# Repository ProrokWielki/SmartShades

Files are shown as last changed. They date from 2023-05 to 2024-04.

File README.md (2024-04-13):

# SmartShades

ESP-12F based project which enables to convert any standard shades into smart shades.

It communicates using mqtt and allows controlling the shades position

### What you need

* ESP-12F - or compatible device
* DRV8220DSG
* motor with encoder
* LM117-3.3
* capacitors and resistors

###

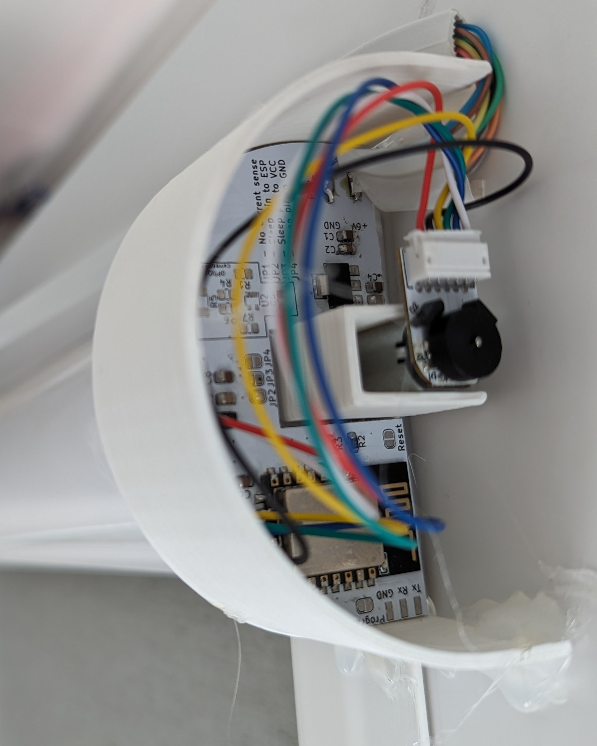
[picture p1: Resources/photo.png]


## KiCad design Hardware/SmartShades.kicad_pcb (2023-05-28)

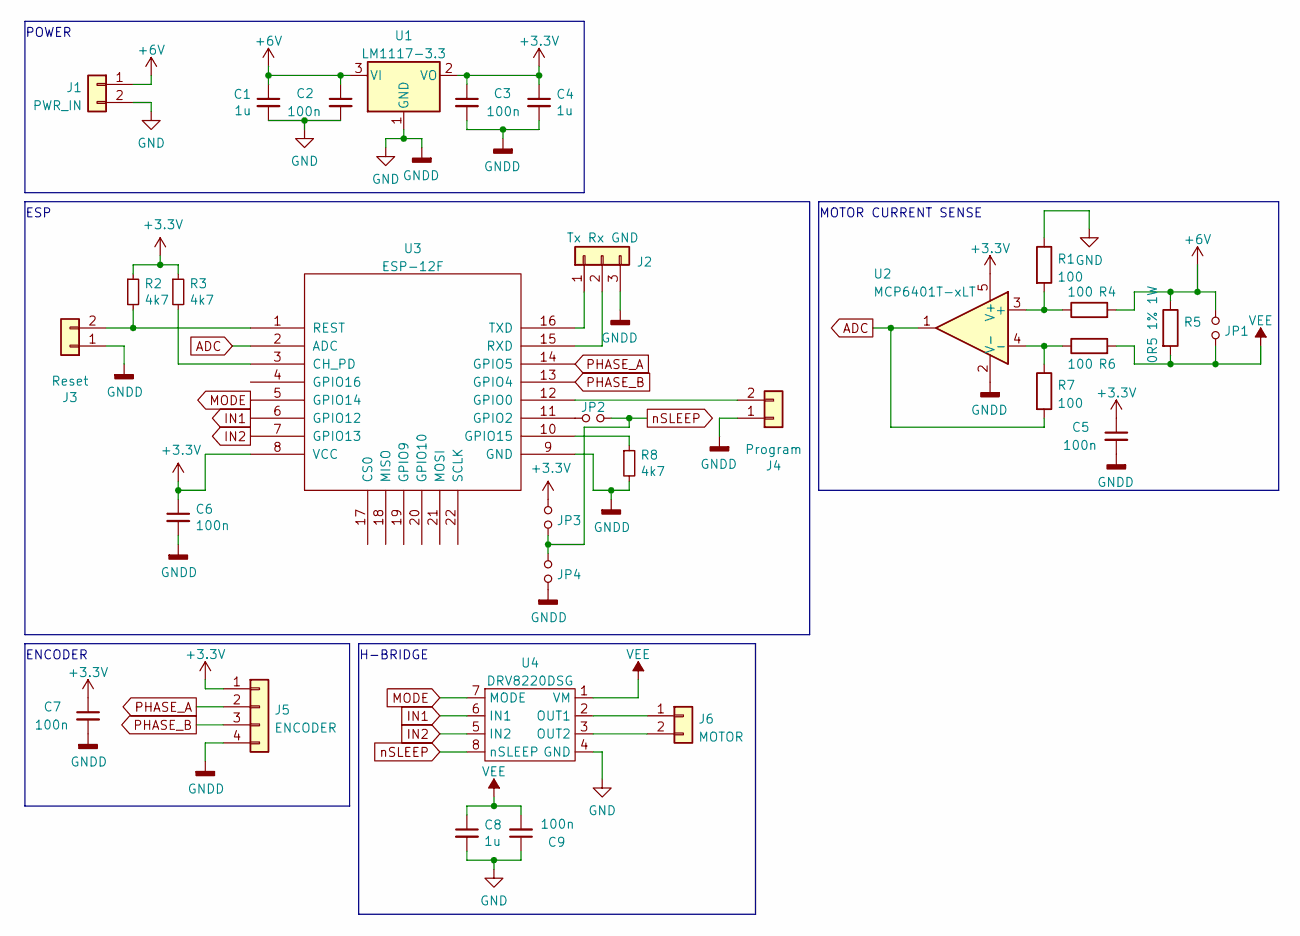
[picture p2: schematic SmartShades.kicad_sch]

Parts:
C1, C4, C8: 1u; C_0805_2012Metric
C2, C3, C5, C6, C7, C9: 100n; C_0805_2012Metric
J1: PWR_IN; TerminalBlock_Altech_AK300-2_P5.00mm
J2: Tx Rx GND; Harwin_M20-89003xx_1x03_P2.54mm_Horizontal
J3: Reset; SolderJumper-2_P1.3mm_Open_RoundedPad1.0x1.5mm
J4: Program; SolderJumper-2_P1.3mm_Open_RoundedPad1.0x1.5mm
J5: ENCODER; Harwin_M20-89004xx_1x04_P2.54mm_Horizontal
J6: MOTOR; Harwin_M20-89003xx_1x03_P2.54mm_Horizontal
JP1, JP2, JP3, JP4: Jumper_NO_Small; SolderJumper-2_P1.3mm_Open_RoundedPad1.0x1.5mm
R1, R4, R6, R7: 100; R_0805_2012Metric
R2, R3, R8: 4k7; R_0805_2012Metric
R5: 0R5 1% 1W; R_1206_3216Metric
U1: LM1117-3.3; SOT-223-3_TabPin2
U2: MCP6401T-xLT; SOT-353_SC-70-5
U3: ESP-12F; ESP-12E_SMD
U4: DRV8220DSG; WSON-8-1EP_2x2mm_P0.5mm_EP0.9x1.6mm

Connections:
+3V3: C3.1, C4.1, C5.1, C6.1, C7.1, J5.1, JP3.1, R2.1, R3.1, U1.2 (VO), U2.5 (V+), U3.8 (VCC)
+6V: C1.1, C2.1, J1.1, JP1.1, R4.2, R5.1, U1.3 (VI)
ADC: R7.2, U2.1, U3.2 (ADC)
GND: C1.2, C2.2, C3.2, C4.2, C5.2, C6.2, C7.2, C8.2, C9.1, J1.2, J2.3, J3.1, J4.1, J5.4, JP4.2, R1.1, R8.2, U1.1 (GND), U2.2 (V-), U3.9 (GND), U4.4 (GND), U4.9 (Pad)
IN1: U3.6 (GPIO12), U4.6 (IN1)
IN2: U3.7 (GPIO13), U4.5 (IN2)
MODE: U3.5 (GPIO14), U4.7 (MODE)
unnamed: J6.1, U4.2 (OUT1)
unnamed: J6.2, U4.3 (OUT2)
unnamed: JP2.1, U3.11 (GPIO2)
unnamed: R1.2, R4.1, U2.3 (+)
unnamed: R6.1, R7.1, U2.4 (-)
unnamed: J3.2, R2.2, U3.1 (REST)
unnamed: R3.2, U3.3 (CH_PD)
unnamed: R8.1, U3.10 (GPIO15)
unnamed: J4.2, U3.12 (GPIO0)
unnamed: J2.2, U3.15 (RXD)
unnamed: J2.1, U3.16 (TXD)
PHASE_A: J5.2, U3.14 (GPIO5)
PHASE_B: J5.3, U3.13 (GPIO4)
VEE: C8.1, C9.2, JP1.2, R5.2, R6.2, U4.1 (VM)
nSLEEP: JP2.2, JP3.2, JP4.1, U4.8 (nSLEEP)

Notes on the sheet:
POWER
MOTOR CURRENT SENSE
ENCODER
H-BRIDGE
ESP

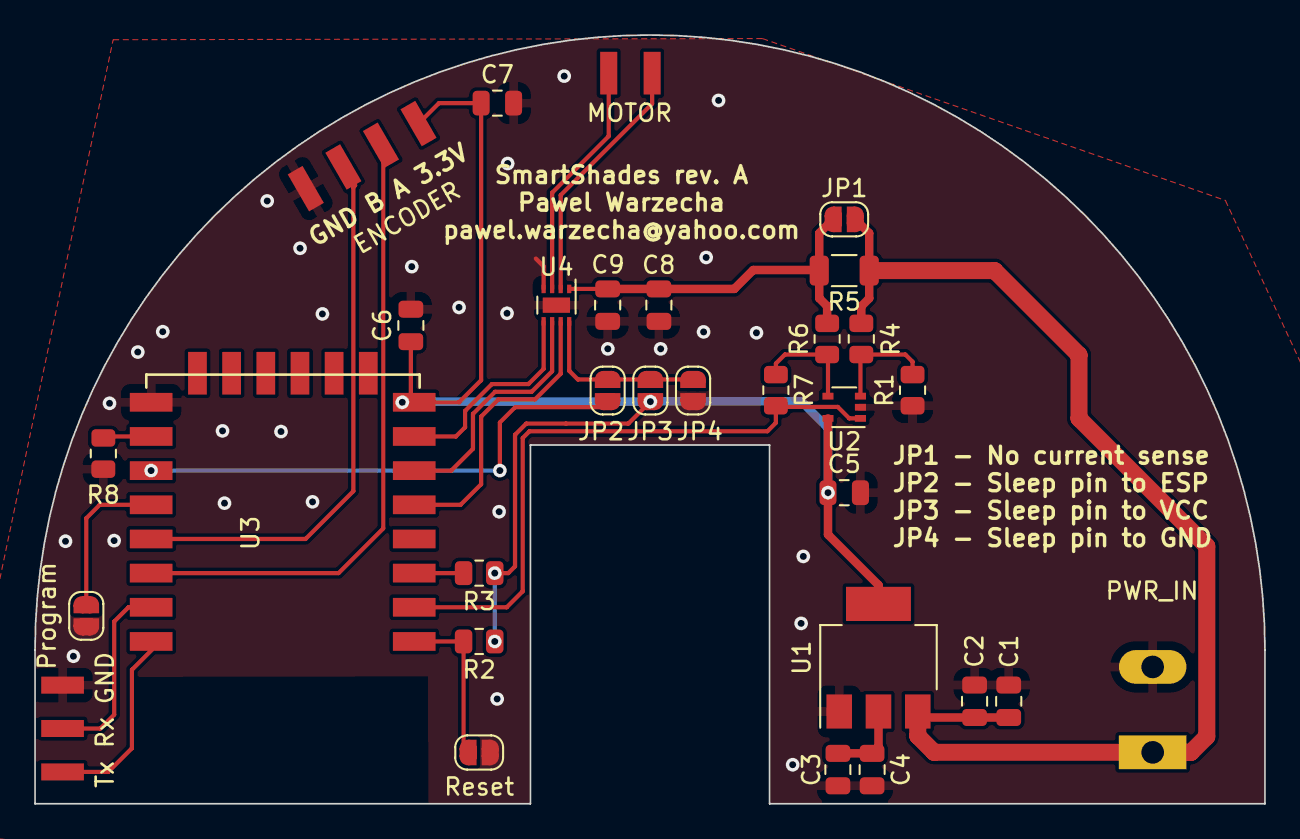
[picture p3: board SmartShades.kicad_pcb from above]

Board: 2 copper layers, 72.0 x 45.0 mm, 31 parts (0 on the bottom side), 22 nets.

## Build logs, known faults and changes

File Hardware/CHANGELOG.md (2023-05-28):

# SmartShades changelog

## Rev. A
* Initial revision

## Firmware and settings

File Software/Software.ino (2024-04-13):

#include <Arduino.h>
#include <ESP8266WiFi.h>
#include <ESPRotary.h>
#include <Ticker.h>
#include <iterator>
#include <string>

#include "esp_utils/config/mqtt_config.h"
#include "esp_utils/config/wifi_config.h"
#include "esp_utils/helpers/mqtt.h"
#include "esp_utils/helpers/ota.h"
#include "esp_utils/helpers/utils.h"

#include "config/DRV8220DSG_config.h"
#include "config/config.h"
#include "config/encoder_config.h"
#include "state_machine.h"

WiFiClient wifi_;
PubSubClient mqtt_(mqtt::server_ip, mqtt::server_port, wifi_);
ESPRotary encoder_;
StateMachine state_machine(drv8220dsg::idle, drv8220dsg::stop, drv8220dsg::down, drv8220dsg::up);
Ticker state_machine_loop, publisher_loop, reconnect_loop;

void check_connection();
void reconnect_if_needed();

std::map<std::string, std::function<void(byte * payload, unsigned int length)>> handle_topic{
{MQTT_TOPIC + "/set",
 [](byte * string, unsigned int length) {
     std::string parsed(reinterpret_cast<char *>(string), length);
     state_machine.request_new_position(atoi(parsed.c_str()));
 }},
{MQTT_TOPIC + "/calibrate", [](byte * string, unsigned int length) { state_machine.request_new_state(StateMachine::State::CALIBRATE); }}};
char numberArray[20];

void setup()
{
    ota::initialize(wifi::hostname);
    WiFi.hostname(wifi::hostname);
    WiFi.begin(wifi::ssid, wifi::password);

    wait_for_initialization([]() { return not(WiFi.status() == WL_CONNECTED); });
    wait_for_initialization([]() { return not(mqtt_.connect(mqtt::client_id)); });

    mqtt_.setCallback([](char * topic, byte * payload, unsigned int length) { handle_topic[topic](payload, length); });
    mqtt_.setKeepAlive(2);
    mqtt_.setSocketTimeout(2);

    mqtt::subscribe(mqtt_, handle_topic);

    drv8220dsg::init();
    encoder::init(encoder_);

    encoder_.loop();

    state_machine_loop.attach_ms(100, []() { state_machine.loop(); });
    publisher_loop.attach_ms(1000, []() {
        if (state_machine.safe_to_publish() and mqtt_.connected())
        {
            itoa(state_machine.get_current_postion(), numberArray, 10);
            mqtt_.publish((MQTT_TOPIC + "/current_position").c_str(), numberArray);
            itoa(state_machine.get_top_position_steps_value(), numberArray, 10);
            mqtt_.publish((MQTT_TOPIC + "/calibration/top_steps_value").c_str(), numberArray);
            itoa(state_machine.get_bottom_position_steps_value(), numberArray, 10);
            mqtt_.publish((MQTT_TOPIC + "/calibration/bottom_steps_value").c_str(), numberArray);
        }
    });
    reconnect_loop.attach_ms(5000, check_connection);
}

void loop()
{

    encoder_.loop();
    state_machine.update_steps_value(encoder_.getPosition());
    ota::handle();
    mqtt_.loop();
    reconnect_if_needed();
}

constexpr auto MAX_RECONNECT_ATTEMPTS = 36;
std::atomic<bool> reconnect_needed = false;
uint8_t reconnect_attempts = 0;

void check_connection()
{
    if (WiFi.status() != WL_CONNECTED)
    {
        reconnect_needed = true;
        return;
    }

    if (not mqtt_.connected())
    {
        reconnect_needed = true;
        return;
    }
}

void reconnect_if_needed()
{
    if (not reconnect_needed)
    {
        return;
    }

    reconnect_needed = false;
    reconnect_attempts++;

    if (reconnect_attempts > MAX_RECONNECT_ATTEMPTS)
    {
        ESP.restart();
    }

    if (WiFi.status() != WL_CONNECTED)
    {
        WiFi.reconnect();
        return;
    }

    if (not mqtt_.connected())
    {
        if (not mqtt_.connect(mqtt::client_id))
        {
            return;
        }
        mqtt::subscribe(mqtt_, handle_topic);
    }
    reconnect_attempts = 0;
}

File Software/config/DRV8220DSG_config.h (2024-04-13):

#pragma once

#include "config.h"

namespace drv8220dsg
{

constexpr auto DRV_SLEEP_PIN = 2;
constexpr auto DRV_MODE_PIN = 14;
constexpr auto DRV_IN1_PIN = 12;
constexpr auto DRV_IN2_PIN = 13;

void down()
{
    digitalWrite(DRV_IN1_PIN, IN1_DOWN_VALUE);
    digitalWrite(DRV_IN2_PIN, !IN1_DOWN_VALUE);
}
void up()
{
    digitalWrite(DRV_IN1_PIN, !IN1_DOWN_VALUE);
    digitalWrite(DRV_IN2_PIN, IN1_DOWN_VALUE);
}
void stop()
{
    digitalWrite(DRV_IN1_PIN, 1);
    digitalWrite(DRV_IN2_PIN, 1);
}

void idle()
{
    digitalWrite(DRV_IN1_PIN, 0);
    digitalWrite(DRV_IN2_PIN, 0);
}

void init()
{
    pinMode(DRV_SLEEP_PIN, OUTPUT);
    pinMode(DRV_MODE_PIN, OUTPUT);
    pinMode(DRV_IN1_PIN, OUTPUT);
    pinMode(DRV_IN2_PIN, OUTPUT);

    digitalWrite(DRV_SLEEP_PIN, HIGH);
    digitalWrite(DRV_MODE_PIN, LOW);

    idle();
}

}  // namespace drv8220dsg

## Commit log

2023-05-27 Schematics for the SmartShades
    [SmartShades.kicad_sch]
2023-05-28 Added pcb
    [SmartShades.kicad_pcb]
2023-05-28 Moved Hardware files one level up
    [SmartShades.kicad_pcb, SmartShades.kicad_sch]
2023-05-28 Gerber files added
2024-04-13 added config for encoder
